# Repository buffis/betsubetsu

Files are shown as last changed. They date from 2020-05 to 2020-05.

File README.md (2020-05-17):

# BetsuBetsu

BetsuBetsu is an Open Source Audio+Video splitter for streaming/recording video from Arcade games (Jamma).

It plugs in between the game and cabinet, and can then be connected to any upscaler + PC for streaming/recording.

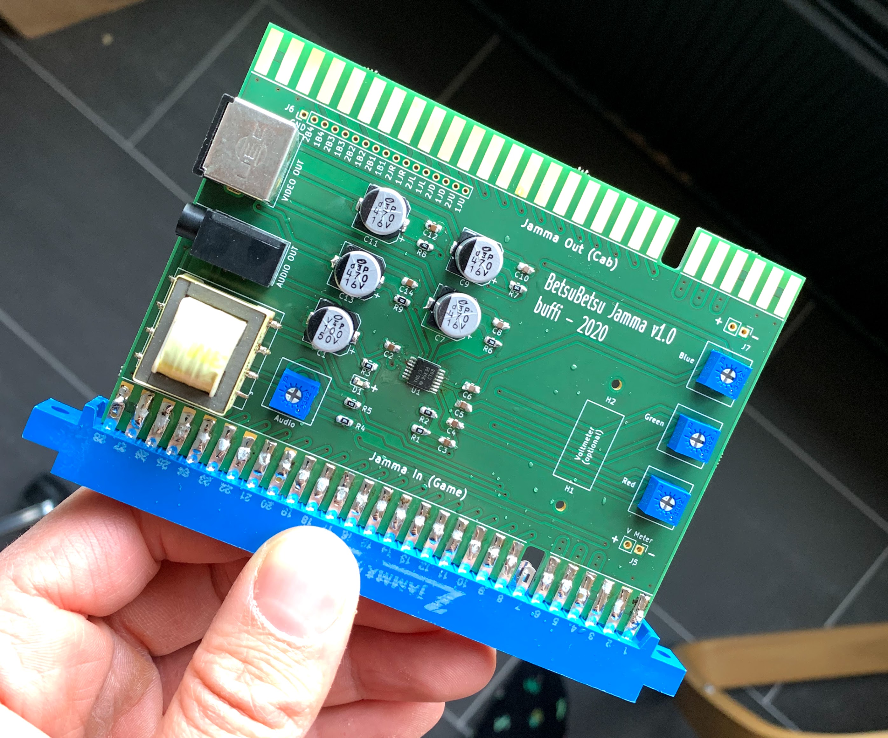
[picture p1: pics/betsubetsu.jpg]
BetsuBetsu


## Features
- MiniDIN 8 RGB video out (same pins as XRGB-Mini, HAS,...), for hooking it up to OSSC.
- Mono audio output through audio jack.
- Adjustable RGB video levels through onboard trimpots.
- Audio gain can be fine tuned through onboard trimpot.
- Power LED
- Optional Voltmeter can be attached

## More detailed features
- Line level audio conversion with galvanic isolation (TY-250P).
- Buffering and unbiasing of Video and Sync signals to safe levels (THS7374). Inputs and outputs are AC-coupled. Safe to drive 75ohm loads / OSSC.
- Audio completely isolated from video (no common ground) to avoid ground loop noise.

## Build instructions

- Order a pcb. Kicad plot files are in the plot/ subdir in the repo.
- Order all parts needed (see BOM)
- Solder it up (suggested order below)
  - Start with THS7374. It's the trickiest footprint to solder.
  - Then do all 0805-sized parts in any order.
  - Solder all five big capacitors. Note that the bottom one is 100uF
  - Solder all trimpots
  - Solder the transformer + output jacks
  - Finally add the Jamma connector (make sure to put it on Jamma In)
- (Optional) Add a voltmeter.

## Installation instructions

1. Insert the BetsuBetsu into the cab jamma harness and connect the game.
2. Connect "Audio Out" to the PC line-in with a stereo cable.
3. Connect "Video Out" to a OSSC or XRGB-Mini with a MINI-DIN8 to SCART cable
4. Connect OSSC/XRGB-Mini to a Capture card (I recomment USB3HDCAP)
5. Capture/Stream in OBS.
6. Calibrate strength of video signals with onboard trimpots
7. Audio output can be fine-adjusted with onboard "Audio" trimpot.

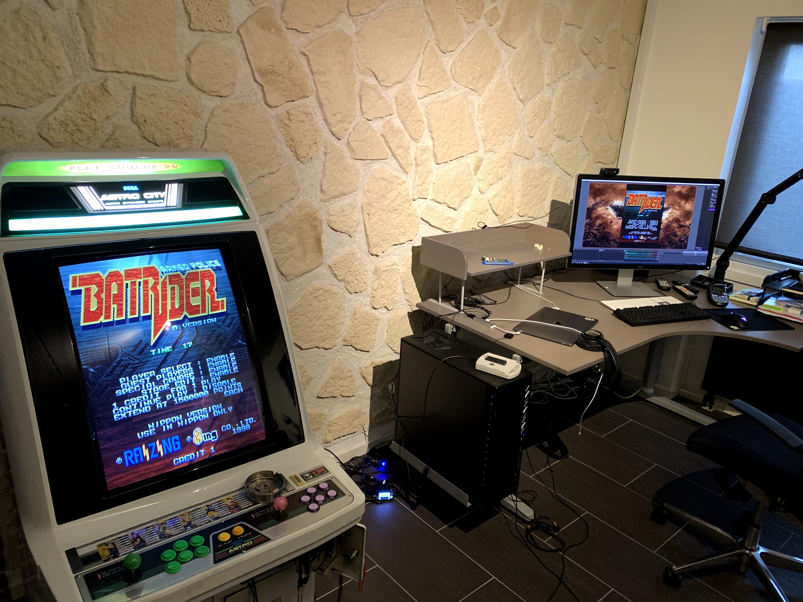
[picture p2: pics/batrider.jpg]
Streaming


## Schematic (v1.0):
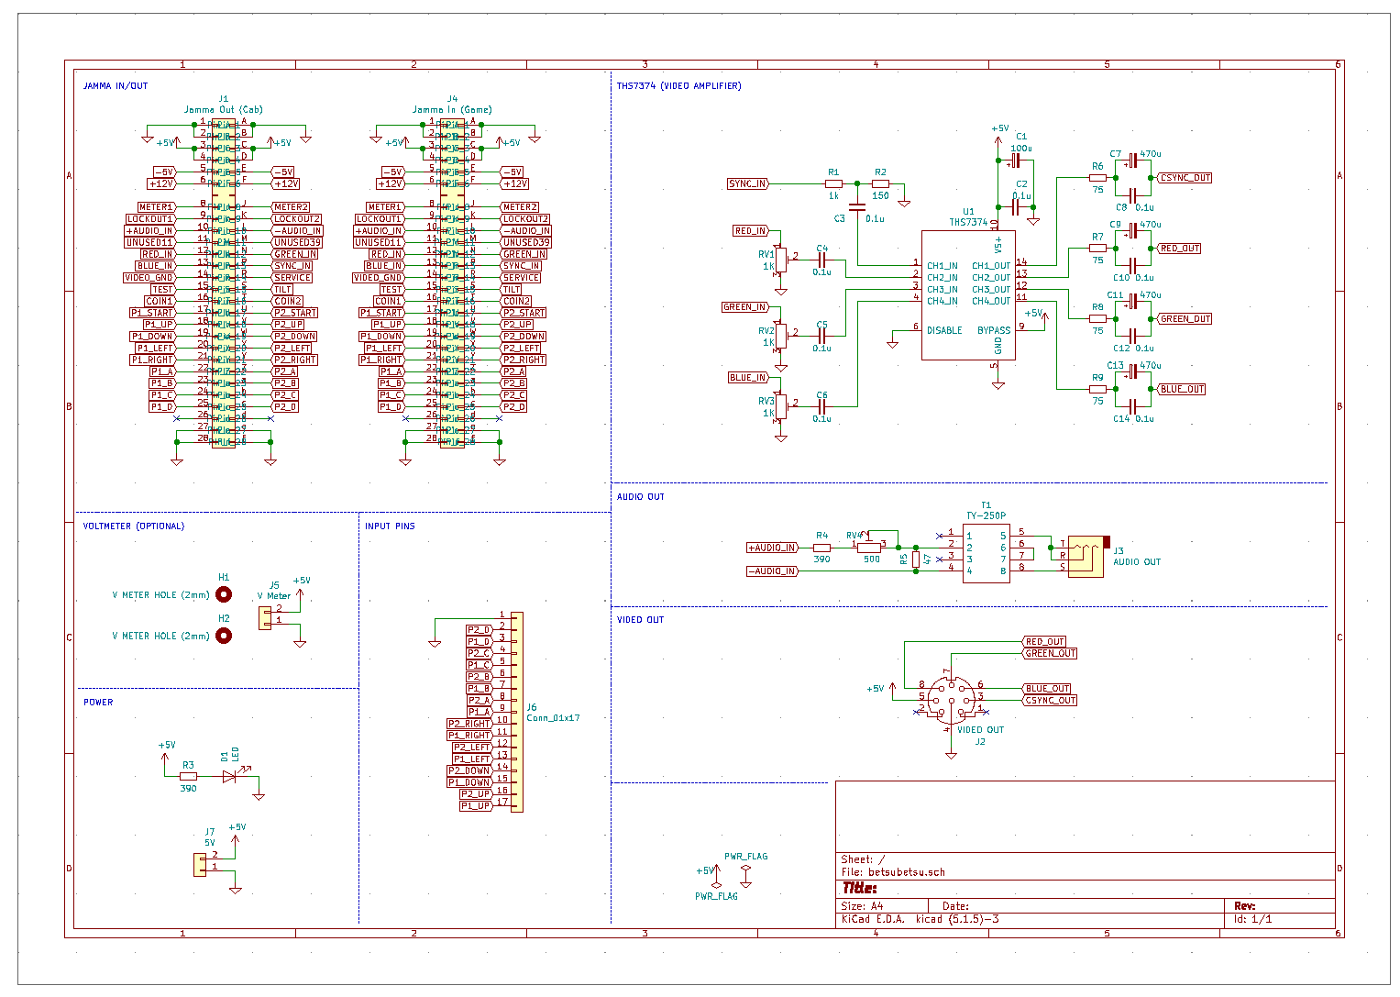
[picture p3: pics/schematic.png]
Schematic


## Board:
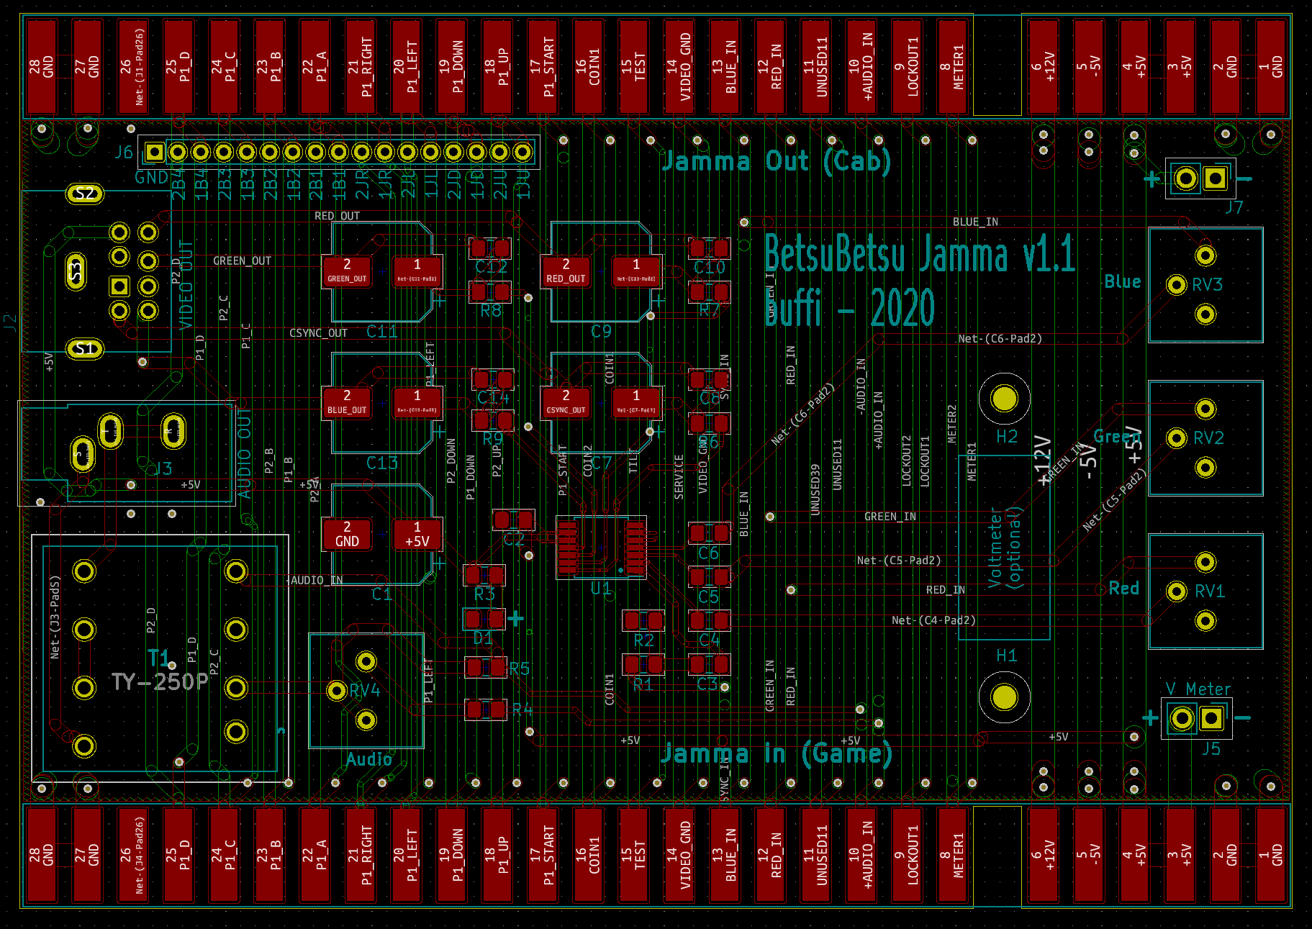
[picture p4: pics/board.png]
Board


## BOM:
https://docs.google.com/spreadsheets/d/1Nb6cgpz1vrsEBL83Tl52jcXvUmsp_AzcXZ7w7m8aYmA/edit?usp=sharing

## Sample capture:
BetsuBetsu + OSSC + Elgato 60 Pro. Scaled to fit inside 1080p in OBS.
Audio is wired from Betsu Betsu to PC Line in directly.
https://www.youtube.com/watch?v=HWDo_Xj9CUc

BetsuBetsu + XRGB-Mini + Elgato 60 Pro. Scaled to fit inside 1080p in OBS.
Audio is wired from Betsu Betsu to PC Line in directly.
https://www.youtube.com/watch?v=Qm8Wi2TviPc

## Misc links:
Arcade-projects thread:
https://www.arcade-projects.com/forums/index.php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

## Misc pics:
Action shot of prototype board in cab:
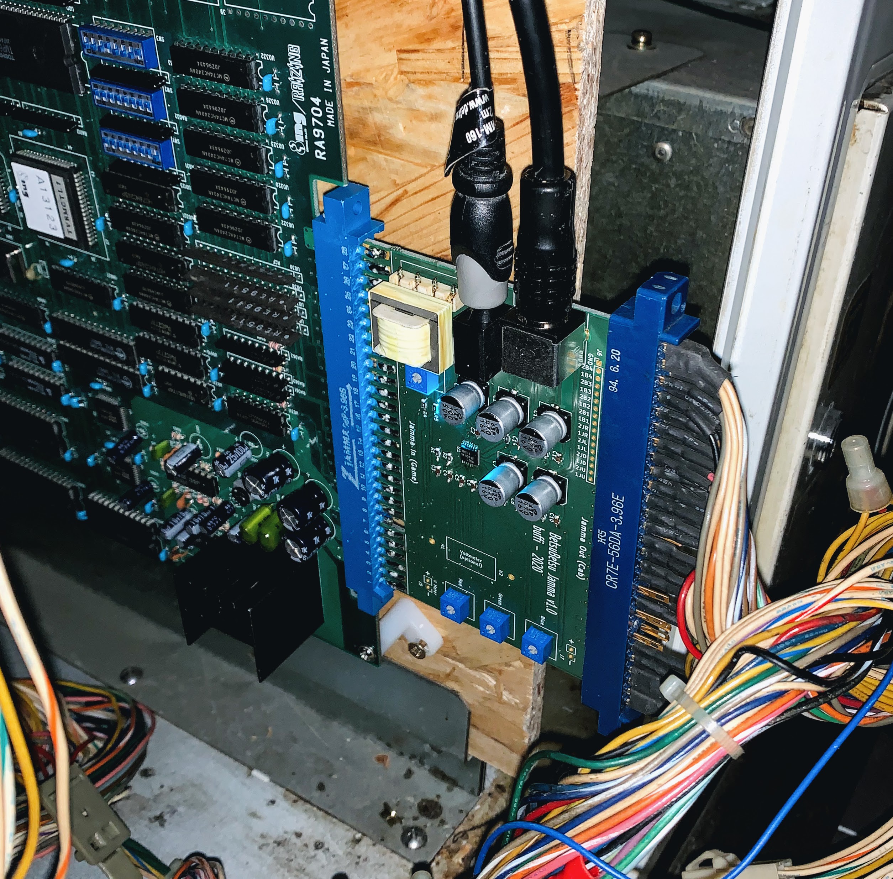
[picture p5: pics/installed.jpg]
Installed PCB


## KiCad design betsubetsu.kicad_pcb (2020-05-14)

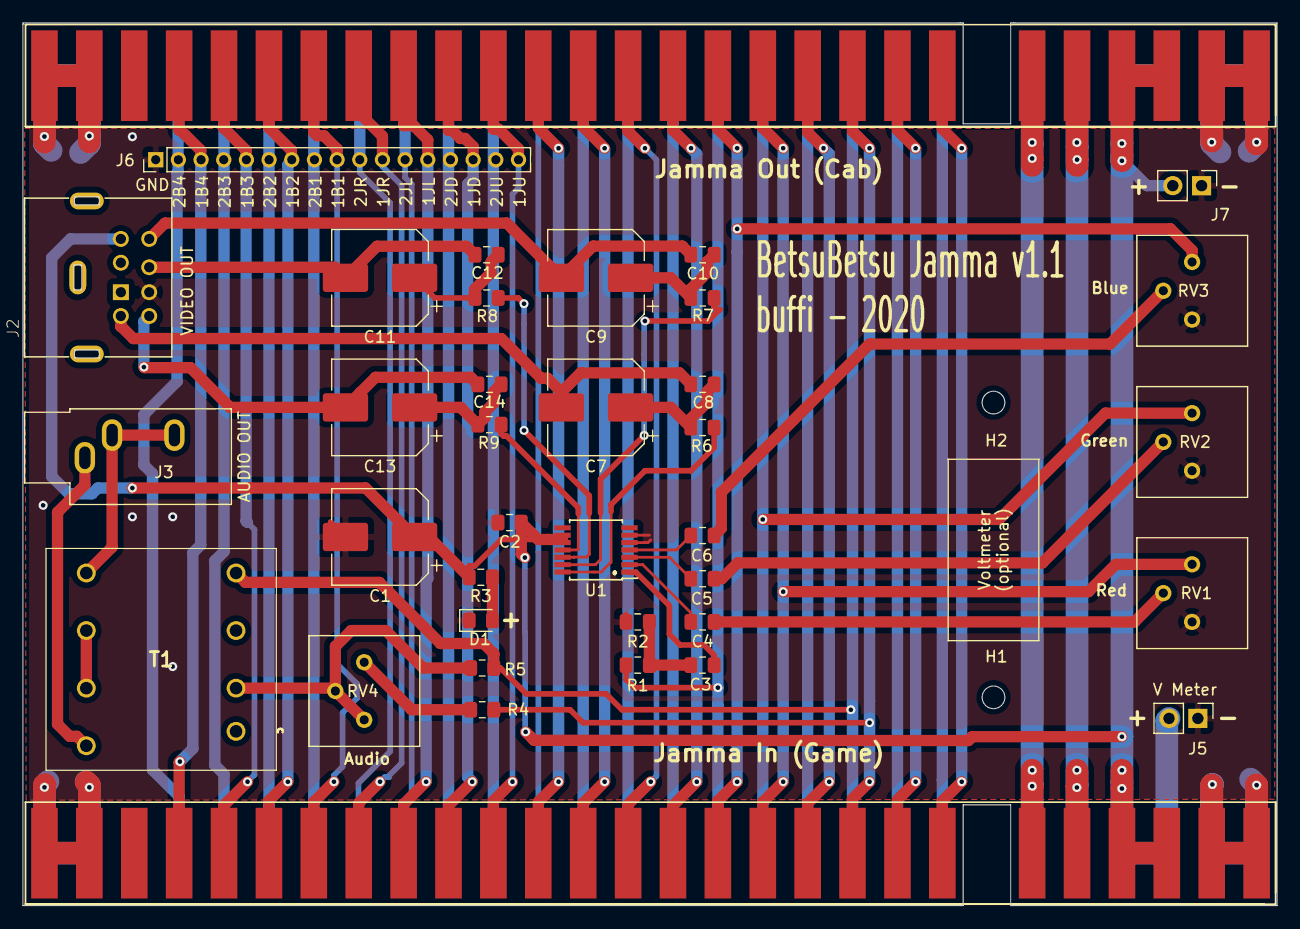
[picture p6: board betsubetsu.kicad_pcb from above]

Board: 2 copper layers, 110.6 x 77.9 mm, 39 parts (0 on the bottom side), 66 nets.

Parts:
C1: 100u; CP_Elec_8x6.7
C2, C3, C4, C5, C6, C8, C10, C12, C14: 0.1u; C_0805_2012Metric_Pad1.15x1.40mm_HandSolder
C7, C9, C11, C13: 470u; CP_Elec_8x6.7
D1: LED; LED_0805_2012Metric_Pad1.15x1.40mm_HandSolder
H1, H2: V METER HOLE (2mm); MountingHole_2mm
J1: Jamma Out (Cab); JAMMA-56
J2: VIDEO OUT; MD-80SM
J3: AUDIO OUT; Jack_3.5mm_CUI_SJ1-3533NG_Horizontal
J4: Jamma In (Game); JAMMA-56
J5: V Meter; PinHeader_1x02_P2.54mm_Vertical
J6: Conn_01x17; PinHeader_1x17_P2.00mm_Vertical
J7: 5V; PinHeader_1x02_P2.54mm_Vertical
R1: 1k; R_0805_2012Metric_Pad1.15x1.40mm_HandSolder
R2: 150; R_0805_2012Metric_Pad1.15x1.40mm_HandSolder
R3, R4: 390; R_0805_2012Metric_Pad1.15x1.40mm_HandSolder
R5: 47; R_0805_2012Metric_Pad1.15x1.40mm_HandSolder
R6, R7, R8, R9: 75; R_0805_2012Metric_Pad1.15x1.40mm_HandSolder
RV1, RV2, RV3: 1K; Potentiometer_Bourns_3386P_Vertical
RV4: 500; Potentiometer_Bourns_3386P_Vertical
T1: TY-250P; TY250P
U1: THS7374; TSSOP-14_4.4x5mm_P0.65mm

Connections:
+5V: C1.1, C2.2, J1.3, J1.4, J1.C, J1.D, J2.5, J4.3, J4.4, J4.C, J4.D, J5.2, J7.2, R3.2, U1.9, U1.10
+12V: J1.6, J1.F, J4.6, J4.F
+AUDIO_IN: J1.10, J4.10, R4.1
-5V: J1.5, J1.E, J4.5, J4.E
-AUDIO_IN: J1.L, J4.L, R5.1, T1.4
BLUE_IN: J1.13, J4.13, RV3.1
BLUE_OUT: C13.2, C14.1, J2.6
COIN1: J1.16, J4.16
COIN2: J1.T, J4.T
CSYNC_OUT: C7.2, C8.1, J2.3
GND: C1.2, C2.1, D1.1, J1.1, J1.2, J1.27, J1.28, J1.A, J1.B, J1.e, J1.f, J2.4, J4.1, J4.2, J4.27, J4.28, J4.A, J4.B, J4.e, J4.f, J5.1, J6.1, J7.1, R2.1, RV1.3, RV2.3, RV3.3, U1.5, U1.6
GREEN_IN: J1.N, J4.N, RV2.1
GREEN_OUT: C11.2, C12.1, J2.7
LOCKOUT1: J1.9, J4.9
LOCKOUT2: J1.K, J4.K
METER1: J1.8, J4.8
METER2: J1.J, J4.J
unnamed: C3.1, U1.1
unnamed: C3.2, R1.1, R2.2
unnamed: C4.1, U1.2
unnamed: C4.2, RV1.2
unnamed: C5.1, U1.3
unnamed: C5.2, RV2.2
unnamed: C6.1, U1.4
unnamed: C6.2, RV3.2
unnamed: C7.1, C8.2, R6.1
unnamed: C9.1, C10.2, R7.1
unnamed: C11.1, C12.2, R8.1
unnamed: C13.1, C14.2, R9.1
unnamed: D1.2, R3.1
unnamed: J3.R, J3.T, T1.5
unnamed: J3.S, T1.8
unnamed: R4.2, RV4.1
unnamed: R5.2, RV4.2, RV4.3, T1.2
unnamed: R6.2, U1.14
unnamed: R7.2, U1.13
unnamed: R8.2, U1.12
unnamed: R9.2, U1.11
unnamed: T1.6, T1.7
P1_A: J1.22, J4.22, J6.9
P1_B: J1.23, J4.23, J6.7
P1_C: J1.24, J4.24, J6.5
P1_D: J1.25, J4.25, J6.3
P1_DOWN: J1.19, J4.19, J6.15
P1_LEFT: J1.20, J4.20, J6.13
P1_RIGHT: J1.21, J4.21, J6.11
P1_START: J1.17, J4.17
P1_UP: J1.18, J4.18, J6.17
P2_A: J1.Z, J4.Z, J6.8
P2_B: J1.a, J4.a, J6.6
P2_C: J1.b, J4.b, J6.4
P2_D: J1.c, J4.c, J6.2
P2_DOWN: J1.W, J4.W, J6.14
P2_LEFT: J1.X, J4.X, J6.12
P2_RIGHT: J1.Y, J4.Y, J6.10
P2_START: J1.U, J4.U
P2_UP: J1.V, J4.V, J6.16
RED_IN: J1.12, J4.12, RV1.1
RED_OUT: C9.2, C10.1, J2.8
SERVICE: J1.R, J4.R
SYNC_IN: J1.P, J4.P, R1.2
TEST: J1.15, J4.15
TILT: J1.S, J4.S
UNUSED11: J1.11, J4.11
UNUSED39: J1.M, J4.M
VIDEO_GND: J1.14, J4.14

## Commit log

2019-09-09 v 0.1
    v 0.1
    [jammasplit.kicad_pcb, jammasplit.sch]
2019-09-20 small fixes
    [jammasplit.kicad_pcb, jammasplit.sch]
2019-09-21 Library cleanup
    [jammasplit.kicad_pcb]
2019-09-22 Gerbers and cleanup
    [betsubetsu-B_Cu.gbr, betsubetsu-B_Mask.gbr, betsubetsu-B_SilkS.gbr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]
2020-05-14 jamma version
    [betsubetsu-B_Cu.gbr, betsubetsu-B_Mask.gbr, betsubetsu-B_SilkS.gbr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]
2020-05-14 Cleaned up jamma version
    [betsubetsu-B_Cu.gbr, betsubetsu-B_Mask.gbr, betsubetsu-B_SilkS.gbr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]
2020-05-26 Create schematic (1).png
2020-06-10 New gerbers
    [betsubetsu-B_Cu.gbr, betsubetsu-B_Mask.gbr, betsubetsu-B_SilkS.gbr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]
